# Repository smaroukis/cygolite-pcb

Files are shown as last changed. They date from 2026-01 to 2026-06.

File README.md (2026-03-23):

PCB (KiCad files + libraries) of a Cygolite bike light (white LED). Constant current driver [MIC4802YME](https://www.digikey.jp/ja/products/detail/microchip-technology/MIC4802YME/2621444) set at 750mA with Li-Ion battery connector and [MCP73831](https://www.digikey.jp/en/products/detail/microchip-technology/MCP73831T-2ACI-OT/964301) Li-Ion charger. ATTiny202 used for PWM output, status LED control and button sensing. USB-C 6P (power only) connector for charging. UART and UDPI pin headers. 

Using 0603 resistor and capacitors for best solderability + size combo.

Demonstration of circuits for multiplexing PWM<>Analog Input and Button Sense <> LED driver.

TODO add photo of the light itself

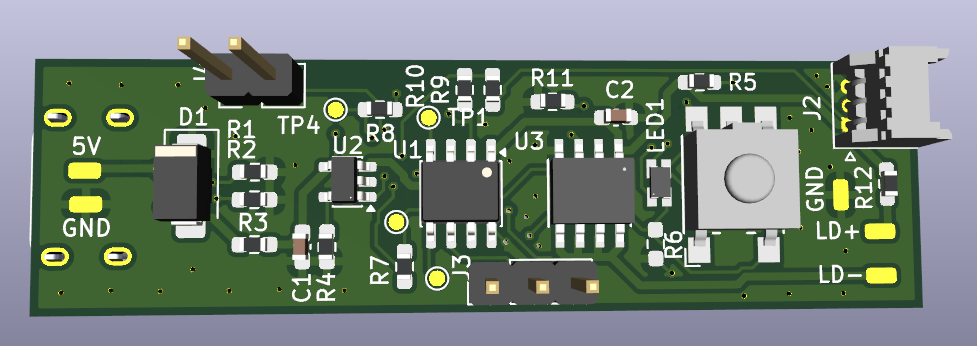
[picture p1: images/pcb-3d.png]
pcb 3d view


## Schematic and Images
See the [Schematic](Schematic.pdf) in `/Schematic.pdf`

PCB - top
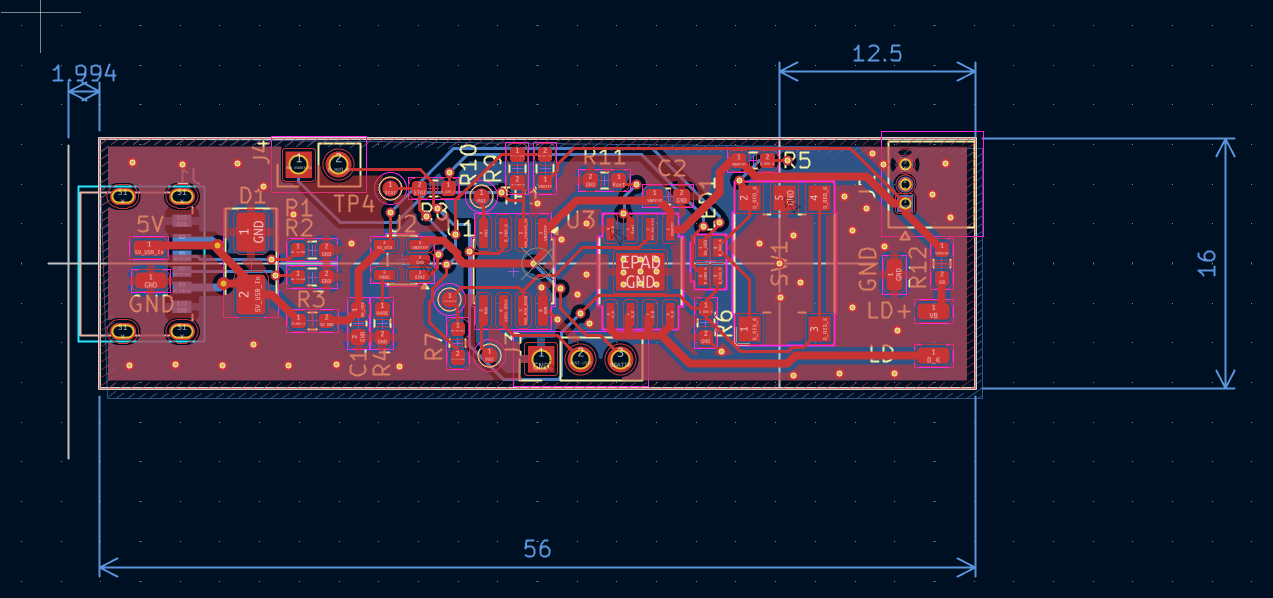
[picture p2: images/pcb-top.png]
pcb top


PCB - 3D top
pcb 3d top

PCB - 3D back (shows USB)
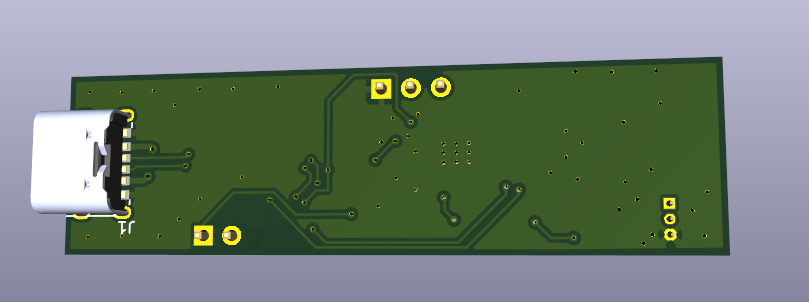
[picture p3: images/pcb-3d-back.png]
pcb 3d back


Close up of battery connector
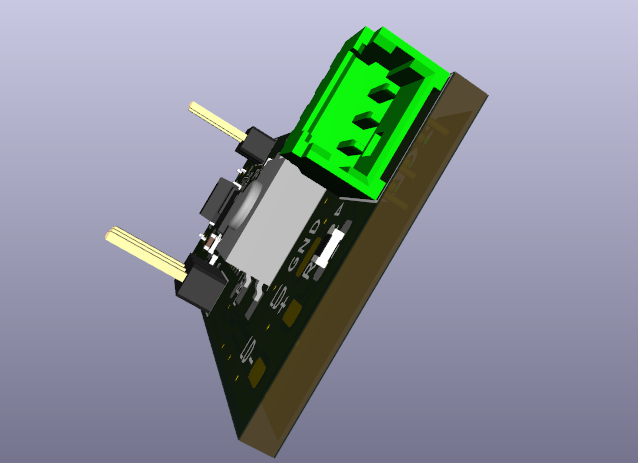
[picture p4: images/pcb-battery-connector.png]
close up battery connector


## BOM

See [BOM.csv][BOM.csv]

| Reference | Qty | Value | MPN | Manufacturer | Description |
|---|-----|---|---|---|---|
| C1,C2 | 2 | 4.7u | (Generic) | (Generic) | Unpolarized capacitor |
| D1 | 1 | SMAJ5.0CA | SMAJ5.0CA | Littelfuse | TVS DIODE 5VWM 9.2VC DO214AC |
| J1 | 1 | USB4125-GF-A-0190 | USB4125-GF-A-0190 | GCT | USB Power-Only 6P Type-C Receptacle connector |
| J2 | 1 | 530480310 | 530480310 | Molex | CONN HEADER R/A 3POS 1.25MM |
| J3 | 1 | Conn_01x03_Socket | N/A | (Generic) | Generic connector, single row, 01x03, script generated |
| J4 | 1 | Conn_01x02_Socket | N/A | (Generic) | Generic connector, single row, 01x02, script generated |
| LED1 | 1 | APHBM2012SURKCGKC | APHBM2012SURKCGKC | Kingbright | LED GREEN/RED CLEAR 2012(mm) SMD |
| R1,R2 | 2 | 5.1K | (Generic) | (Generic) | Resistor 0603 5.1K |
| R3,R12 | 2 | 0 | (Generic) | (Generic) | Resistor 0603 0Ohm |
| R4,R5,R8  | 3 | 2K | (Generic) | (Generic) | Resistor 0603 2KOhm |
| R6 | 1 | 1M | (Generic) | (Generic) | Resistor |
| R7,R9,R10 | 3 | 10K | (Generic) | (Generic) | Resistor 0603 10KOhm |
| R11 | 1 | 6.8K | (Generic) | (Generic) | Resistor 0603 6.8K 1% |
| SW1 | 1 | SW_Push | FSM1LPTR | TE Connectivity ALCOSWITCH Switches | Generic push-button switch, two contact pins and shield pin(s) |
| U1 | 1 | ATtiny202-SS | ATTINY202-SSN-ND  | Microchip Technology | 20MHz, 2kB Flash, 128B SRAM, 64B EEPROM, SOIC-8 |
| U2 | 1 | MCP73831-2-OT | MCP73831T-2ACI/OT | Microchip Technology | Single cell, Li-Ion/Li-Po charge management controller, 4.20V, Tri-State Status Output, in SOT23-5 package |
| U3 | 1 | MIC4802YME | MIC4802YME | Microchip Technology | LED Driver IC 1 Output Linear PWM Dimming 800mA 8-SOIC-EP |

## TODOs
- [ ] add schematic pdfs and board image
- [ ] add multiplexing superposition explanation

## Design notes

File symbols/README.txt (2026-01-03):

Instructions
Keep One Collocated File for all project symbols.
Append New Symbols as needed. 
Add just this .kicad_sym file to the Project's Symbol Library Path.
For auto-reuse across Projects use ${KIPRJMOD}/symbols/project_symbols.kicad_sym

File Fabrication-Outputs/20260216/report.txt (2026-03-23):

Warning: Width correction constrained.  The width correction value must be in the range of [0.000001 mm; -0.000002 mm] for the current design rules.
Plotted to '/home/spencer/Applications/KiCad/Cygolite-Clone/Fabrication-Outputs/20260216/Cygolite-Clone-F_Cu.gbr'.
Plotted to '/home/spencer/Applications/KiCad/Cygolite-Clone/Fabrication-Outputs/20260216/Cygolite-Clone-B_Cu.gbr'.
Plotted to '/home/spencer/Applications/KiCad/Cygolite-Clone/Fabrication-Outputs/20260216/Cygolite-Clone-F_Paste.gbr'.
Plotted to '/home/spencer/Applications/KiCad/Cygolite-Clone/Fabrication-Outputs/20260216/Cygolite-Clone-B_Paste.gbr'.
Plotted to '/home/spencer/Applications/KiCad/Cygolite-Clone/Fabrication-Outputs/20260216/Cygolite-Clone-F_Silkscreen.gbr'.
Plotted to '/home/spencer/Applications/KiCad/Cygolite-Clone/Fabrication-Outputs/20260216/Cygolite-Clone-B_Silkscreen.gbr'.
Plotted to '/home/spencer/Applications/KiCad/Cygolite-Clone/Fabrication-Outputs/20260216/Cygolite-Clone-F_Mask.gbr'.
Plotted to '/home/spencer/Applications/KiCad/Cygolite-Clone/Fabrication-Outputs/20260216/Cygolite-Clone-B_Mask.gbr'.
Plotted to '/home/spencer/Applications/KiCad/Cygolite-Clone/Fabrication-Outputs/20260216/Cygolite-Clone-Edge_Cuts.gbr'.
Created Gerber job file '/home/spencer/Applications/KiCad/Cygolite-Clone/Fabrication-Outputs/20260216/Cygolite-Clone-job.gbrjob'.
Info: Done.
Info: Done.

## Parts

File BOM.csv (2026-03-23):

Reference | Qty | Value | MPN | Manufacturer | Description | Footprint | Supplier 1 | Supplier 1 URL
C1,C2 | 2 | 4.7u | (Generic) | (Generic) | Unpolarized capacitor | Capacitor_SMD:C_0603_1608Metric_Pad1.08x0.95mm_HandSolder | (Generic)
D1 | 1 | SMAJ5.0CA | SMAJ5.0CA | Littelfuse | TVS DIODE 5VWM 9.2VC DO214AC | Diode_SMD:D_SMA | Digikey | https://www.digikey.jp/en/products/detail/littelfuse-inc/SMAJ5-0CA/762251
J1 | 1 | USB4125-GF-A-0190 | USB4125-GF-A-0190 | GCT | USB Power-Only 6P Type-C Receptacle connector | a_project_footprints:CONN6_125-GF-A-0190_GCT | Digikey | https://www.digikey.jp/en/products/detail/gct/USB4125-GF-A-0190/14559038
J2 | 1 | 530480310 | 530480310 | Molex | CONN HEADER R/A 3POS 1.25MM | a_project_footprints:MOLEX_530480310 | Digikey | https://www.digikey.jp/en/products/detail/molex/0530480310/242865?s=N4IgTCBcDaIKwGYAMAWAHEhBGJIC6AvkA
J3 | 1 | Conn_01x03_Socket | N/A | (Generic) | Generic connector, single row, 01x03, script generated | Connector_PinHeader_2.54mm:PinHeader_1x03_P2.54mm_Vertical | (Generic)
J4 | 1 | Conn_01x02_Socket | N/A | (Generic) | Generic connector, single row, 01x02, script generated | Connector_PinHeader_2.54mm:PinHeader_1x02_P2.54mm_Vertical | (Generic)
LED1 | 1 | APHBM2012SURKCGKC | APHBM2012SURKCGKC | Kingbright | LED GREEN/RED CLEAR 2012(mm) SMD | a_project_footprints:APHBM2012_KNB | Digikey | https://www.digikey.jp/ja/products/detail/kingbright/APHBM2012SURKCGKC/1747491
R1,R2 | 2 | 5.1K | (Generic) | (Generic) | Resistor 0603 5.1K | Resistor_SMD:R_0603_1608Metric_Pad0.98x0.95mm_HandSolder | (Generic)
R3,R12 | 2 | 0 | (Generic) | (Generic) | Resistor 0603 0Ohm | Resistor_SMD:R_0603_1608Metric_Pad0.98x0.95mm_HandSolder | (Generic)
R4,R5,R8 | 3 | 2K | (Generic) | (Generic) | Resistor 0603 2KOhm | Resistor_SMD:R_0603_1608Metric_Pad0.98x0.95mm_HandSolder | (Generic)
R6 | 1 | 1M | (Generic) | (Generic) | Resistor | Resistor_SMD:R_0603_1608Metric_Pad0.98x0.95mm_HandSolder | (Generic)
R7,R9,R10 | 3 | 10K | (Generic) | (Generic) | Resistor 0603 10KOhm | Resistor_SMD:R_0603_1608Metric_Pad0.98x0.95mm_HandSolder | (Generic)
R11 | 1 | 6.8K | (Generic) | (Generic) | Resistor 0603 6.8K 1% | Resistor_SMD:R_0603_1608Metric_Pad0.98x0.95mm_HandSolder | (Generic)
SW1 | 1 | SW_Push | FSM1LPTR | TE Connectivity ALCOSWITCH Switches | Generic push-button switch, two contact pins and shield pin(s) | a_project_footprints:SWITCH_FSM1LPA_TYC | Digikey | https://www.digikey.jp/en/products/detail/te-connectivity-alcoswitch-switches/FSM1LPTR/529676?gclsrc=aw.ds
U1 | 1 | ATtiny202-SS | ATTINY202-SSN-ND | Microchip Technology | 20MHz, 2kB Flash, 128B SRAM, 64B EEPROM, SOIC-8 | Package_SO:SOIC-8_3.9x4.9mm_P1.27mm | Digikey | https://www.digikey.jp/ja/products/detail/microchip-technology/ATTINY202-SSN/9947534
U2 | 1 | MCP73831-2-OT | MCP73831T-2ACI/OT | Microchip Technology | Single cell, Li-Ion/Li-Po charge management controller, 4.20V, Tri-State Status Output, in SOT23-5 package | Package_TO_SOT_SMD:SOT-23-5 | Digikey | https://www.digikey.jp/en/products/detail/microchip-technology/MCP73831T-2ACI-OT/964301
U3 | 1 | MIC4802YME | MIC4802YME | Microchip Technology | LED Driver IC 1 Output Linear PWM Dimming 800mA 8-SOIC-EP | a_project_footprints:SOIC-8_ME_MCL | Digikey | https://www.digikey.jp/ja/products/detail/microchip-technology/MIC4802YME/2621444

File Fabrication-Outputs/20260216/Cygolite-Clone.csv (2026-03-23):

Reference | Qty | Value | Description | Footprint | MPN | Manufacturer | Supplier 1 | Supplier 1 SKU | Supplier 1 URL
C1,C2 | 2 | 4.7u | Unpolarized capacitor | Capacitor_SMD:C_0603_1608Metric_Pad1.08x0.95mm_HandSolder | (Generic) | (Generic) | (Generic)
D1 | 1 | SMAJ5.0CA | TVS DIODE 5VWM 9.2VC DO214AC | Diode_SMD:D_SMA | SMAJ5.0CA | Littelfuse | Digikey |  | https://www.digikey.jp/en/products/detail/littelfuse-inc/SMAJ5-0CA/762251
J1 | 1 | USB4125-GF-A-0190 | USB Power-Only 6P Type-C Receptacle connector | a_project_footprints:CONN6_125-GF-A-0190_GCT | USB4125-GF-A-0190 | GCT | Digikey |  | https://www.digikey.jp/en/products/detail/gct/USB4125-GF-A-0190/14559038
J2 | 1 | 530480310 | CONN HEADER R/A 3POS 1.25MM | a_project_footprints:MOLEX_530480310 | 530480310 | Molex | Digikey |  | https://www.digikey.jp/en/products/detail/molex/0530480310/242865?s=N4IgTCBcDaIKwGYAMAWAHEhBGJIC6AvkA
J3 | 1 | Conn_01x03_Socket | Generic connector, single row, 01x03, script generated | Connector_PinHeader_2.54mm:PinHeader_1x03_P2.54mm_Vertical | N/A
J4 | 1 | Conn_01x02_Socket | Generic connector, single row, 01x02, script generated | Connector_PinHeader_2.54mm:PinHeader_1x02_P2.54mm_Vertical | N/A
LED1 | 1 | APHBM2012SURKCGKC | LED GREEN/RED CLEAR 2012(mm) SMD | a_project_footprints:APHBM2012_KNB | APHBM2012SURKCGKC | Kingbright | Digikey |  | https://www.digikey.jp/ja/products/detail/kingbright/APHBM2012SURKCGKC/1747491
R1,R2 | 2 | 5.1K | Resistor 0603 5.1K | Resistor_SMD:R_0603_1608Metric_Pad0.98x0.95mm_HandSolder | (Generic)
R3,R12 | 2 | 0 | Resistor 0603 0Ohm | Resistor_SMD:R_0603_1608Metric_Pad0.98x0.95mm_HandSolder | (Generic)
R4,R5,R8 | 3 | 2K | Resistor 0603 2KOhm | Resistor_SMD:R_0603_1608Metric_Pad0.98x0.95mm_HandSolder | (Generic) | (Generic) | (Generic)
R6 | 1 | 1M | Resistor | Resistor_SMD:R_0603_1608Metric_Pad0.98x0.95mm_HandSolder | (Generic) | (Generic) | (Generic)
R7,R9,R10 | 3 | 10K | Resistor 0603 10KOhm | Resistor_SMD:R_0603_1608Metric_Pad0.98x0.95mm_HandSolder | (Generic) | (Generic) | (Generic)
R11 | 1 | 6.8K | Resistor 0603 6.8K 1% | Resistor_SMD:R_0603_1608Metric_Pad0.98x0.95mm_HandSolder | (Generic) | (Generic) | (Generic)
SP1 | 1 | P+ | test point | Connector_Wire:SolderWirePad_1x01_SMD_1x2mm | N/A
SP2 | 1 | P- | test point | Connector_Wire:SolderWirePad_1x01_SMD_1x2mm | N/A
SP3 | 1 | GND | test point | Connector_Wire:SolderWirePad_1x01_SMD_1x2mm | N/A
SP4 | 1 | 5V | test point | Connector_Wire:SolderWirePad_1x01_SMD_1x2mm | N/A
SP6 | 1 | LED_K | test point | Connector_Wire:SolderWirePad_1x01_SMD_1x2mm | N/A
SW1 | 1 | SW_Push | Generic push-button switch, two contact pins and shield pin(s) | a_project_footprints:SWITCH_FSM1LPA_TYC | FSM1LPTR | TE Connectivity ALCOSWITCH Switches | Digikey |  | https://www.digikey.jp/en/products/detail/te-connectivity-alcoswitch-switches/FSM1LPTR/529676?gclsrc=aw.ds
TP1,TP2,TP3 | 3 | U2_VDD | test point | TestPoint:TestPoint_Pad_D1.0mm | N/A
TP4 | 1 | STAT | test point | TestPoint:TestPoint_Pad_D1.0mm | N/A
U1 | 1 | ATtiny202-SS | 20MHz, 2kB Flash, 128B SRAM, 64B EEPROM, SOIC-8 | Package_SO:SOIC-8_3.9x4.9mm_P1.27mm | ATTINY202-SSN-ND | Microchip Technology | Digikey |  | https://www.digikey.jp/ja/products/detail/microchip-technology/ATTINY202-SSN/9947534
U2 | 1 | MCP73831-2-OT | Single cell, Li-Ion/Li-Po charge management controller, 4.20V, Tri-State Status Output, in SOT23-5 package | Package_TO_SOT_SMD:SOT-23-5 | MCP73831T-2ACI/OT | Microchip Technology | Digikey |  | https://www.digikey.jp/en/products/detail/microchip-technology/MCP73831T-2ACI-OT/964301
U3 | 1 | MIC4802YME | LED Driver IC 1 Output Linear PWM Dimming 800mA 8-SOIC-EP | a_project_footprints:SOIC-8_ME_MCL | MIC4802YME | Microchip Technology | Digikey |  | https://www.digikey.jp/ja/products/detail/microchip-technology/MIC4802YME/2621444

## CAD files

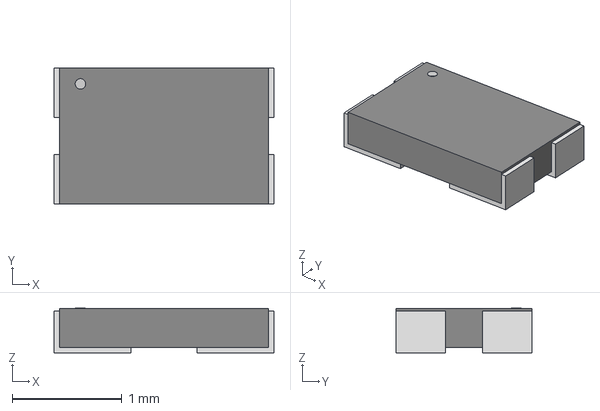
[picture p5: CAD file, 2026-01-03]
3dmodels/APHBM2012_KNB.step
2.01 x 1.24 x 0.409 mm

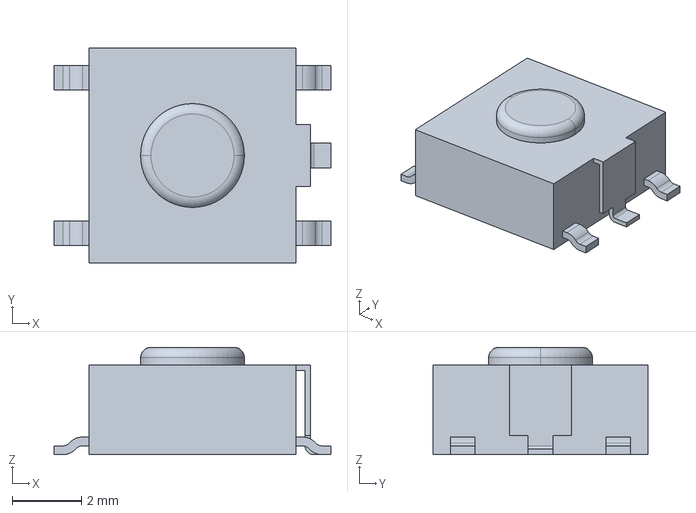
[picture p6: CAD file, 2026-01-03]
imports_source/FSM1LPTR/FSM1LPTR_PB_c-1-1437565-9-d1-3d.stp
8.00 x 6.20 x 3.10 mm

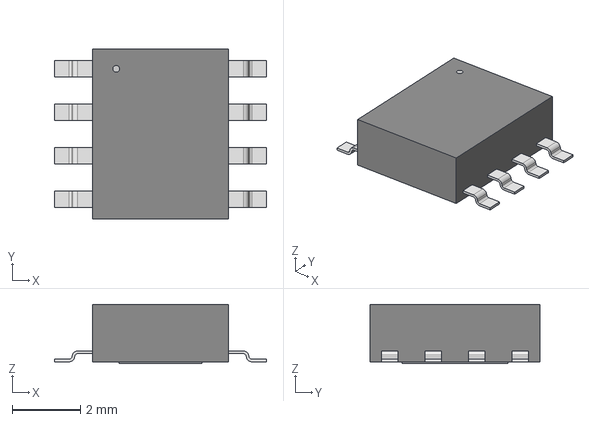
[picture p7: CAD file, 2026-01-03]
imports_source/MIC4802YME/SOIC-8_ME_MCL.step
6.20 x 4.98 x 1.73 mm

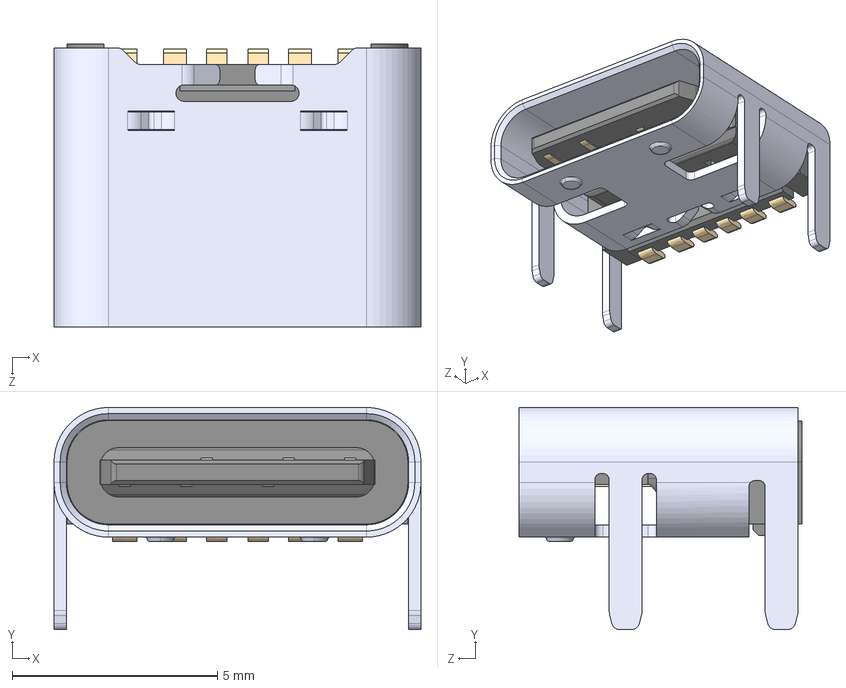
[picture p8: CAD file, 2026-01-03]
imports_source/USB4125_GF_A_0190/USB4125-GF-A-0190_REVA2.step
8.94 x 5.41 x 6.90 mm

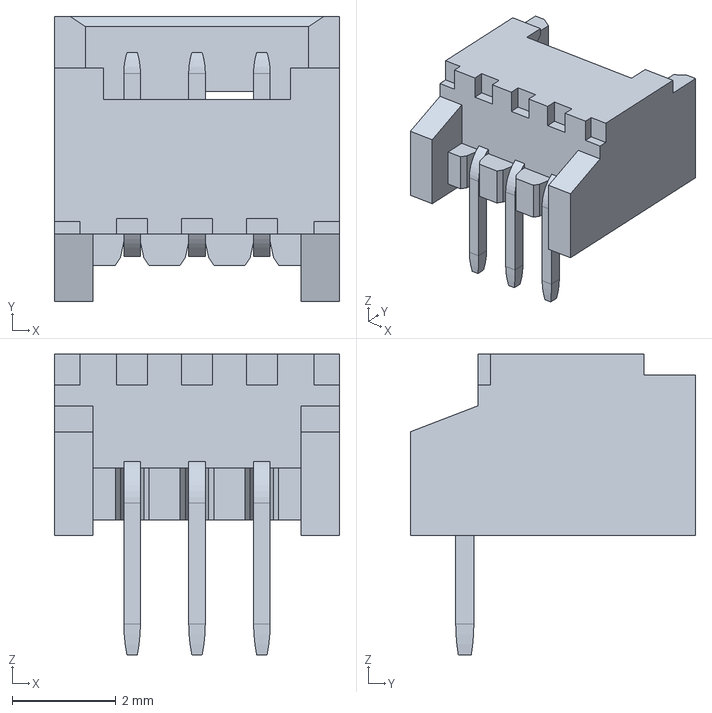
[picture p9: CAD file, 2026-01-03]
imports_source/Molex_530480310/530480310.step
5.50 x 5.50 x 5.80 mm

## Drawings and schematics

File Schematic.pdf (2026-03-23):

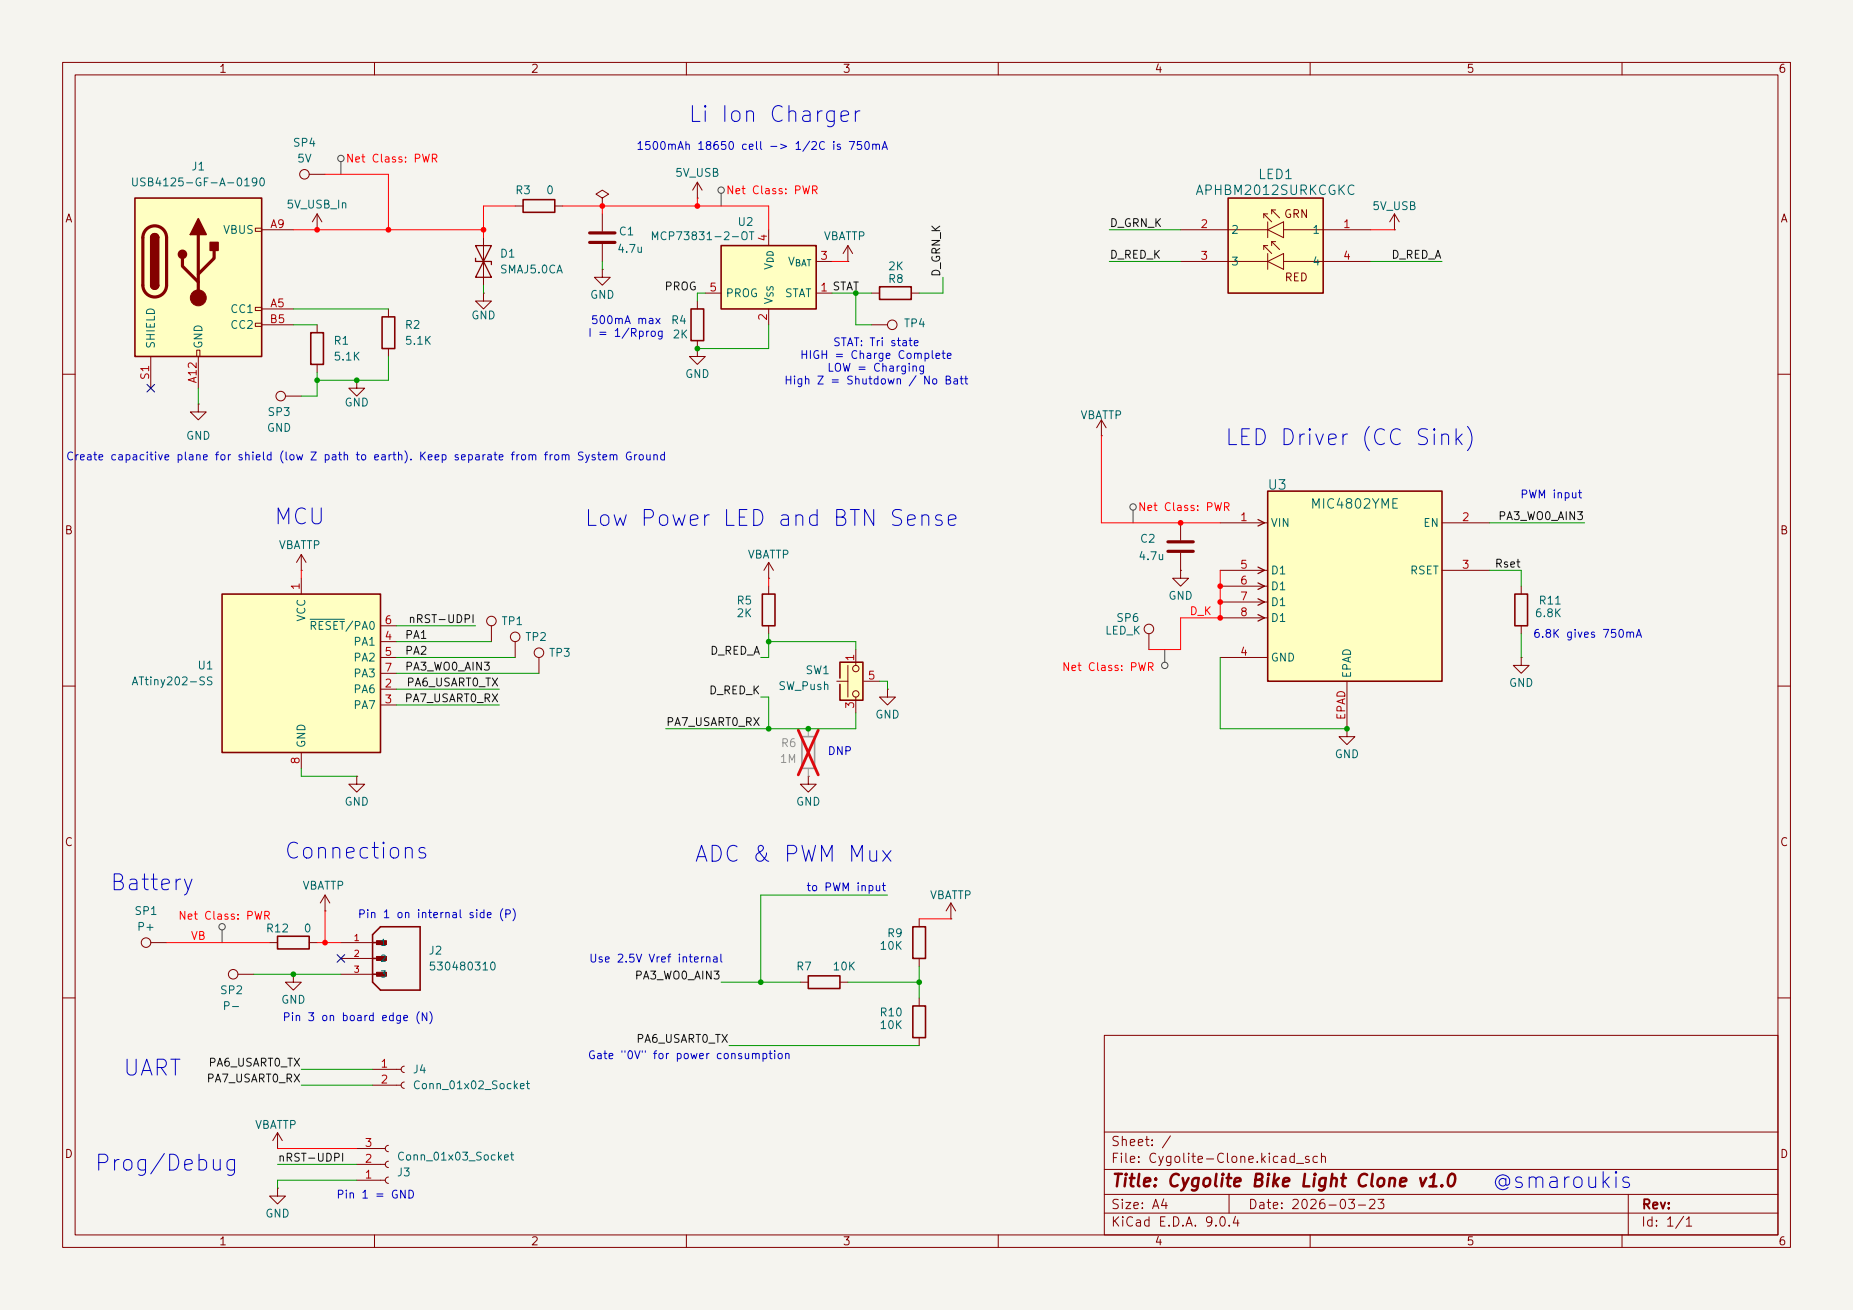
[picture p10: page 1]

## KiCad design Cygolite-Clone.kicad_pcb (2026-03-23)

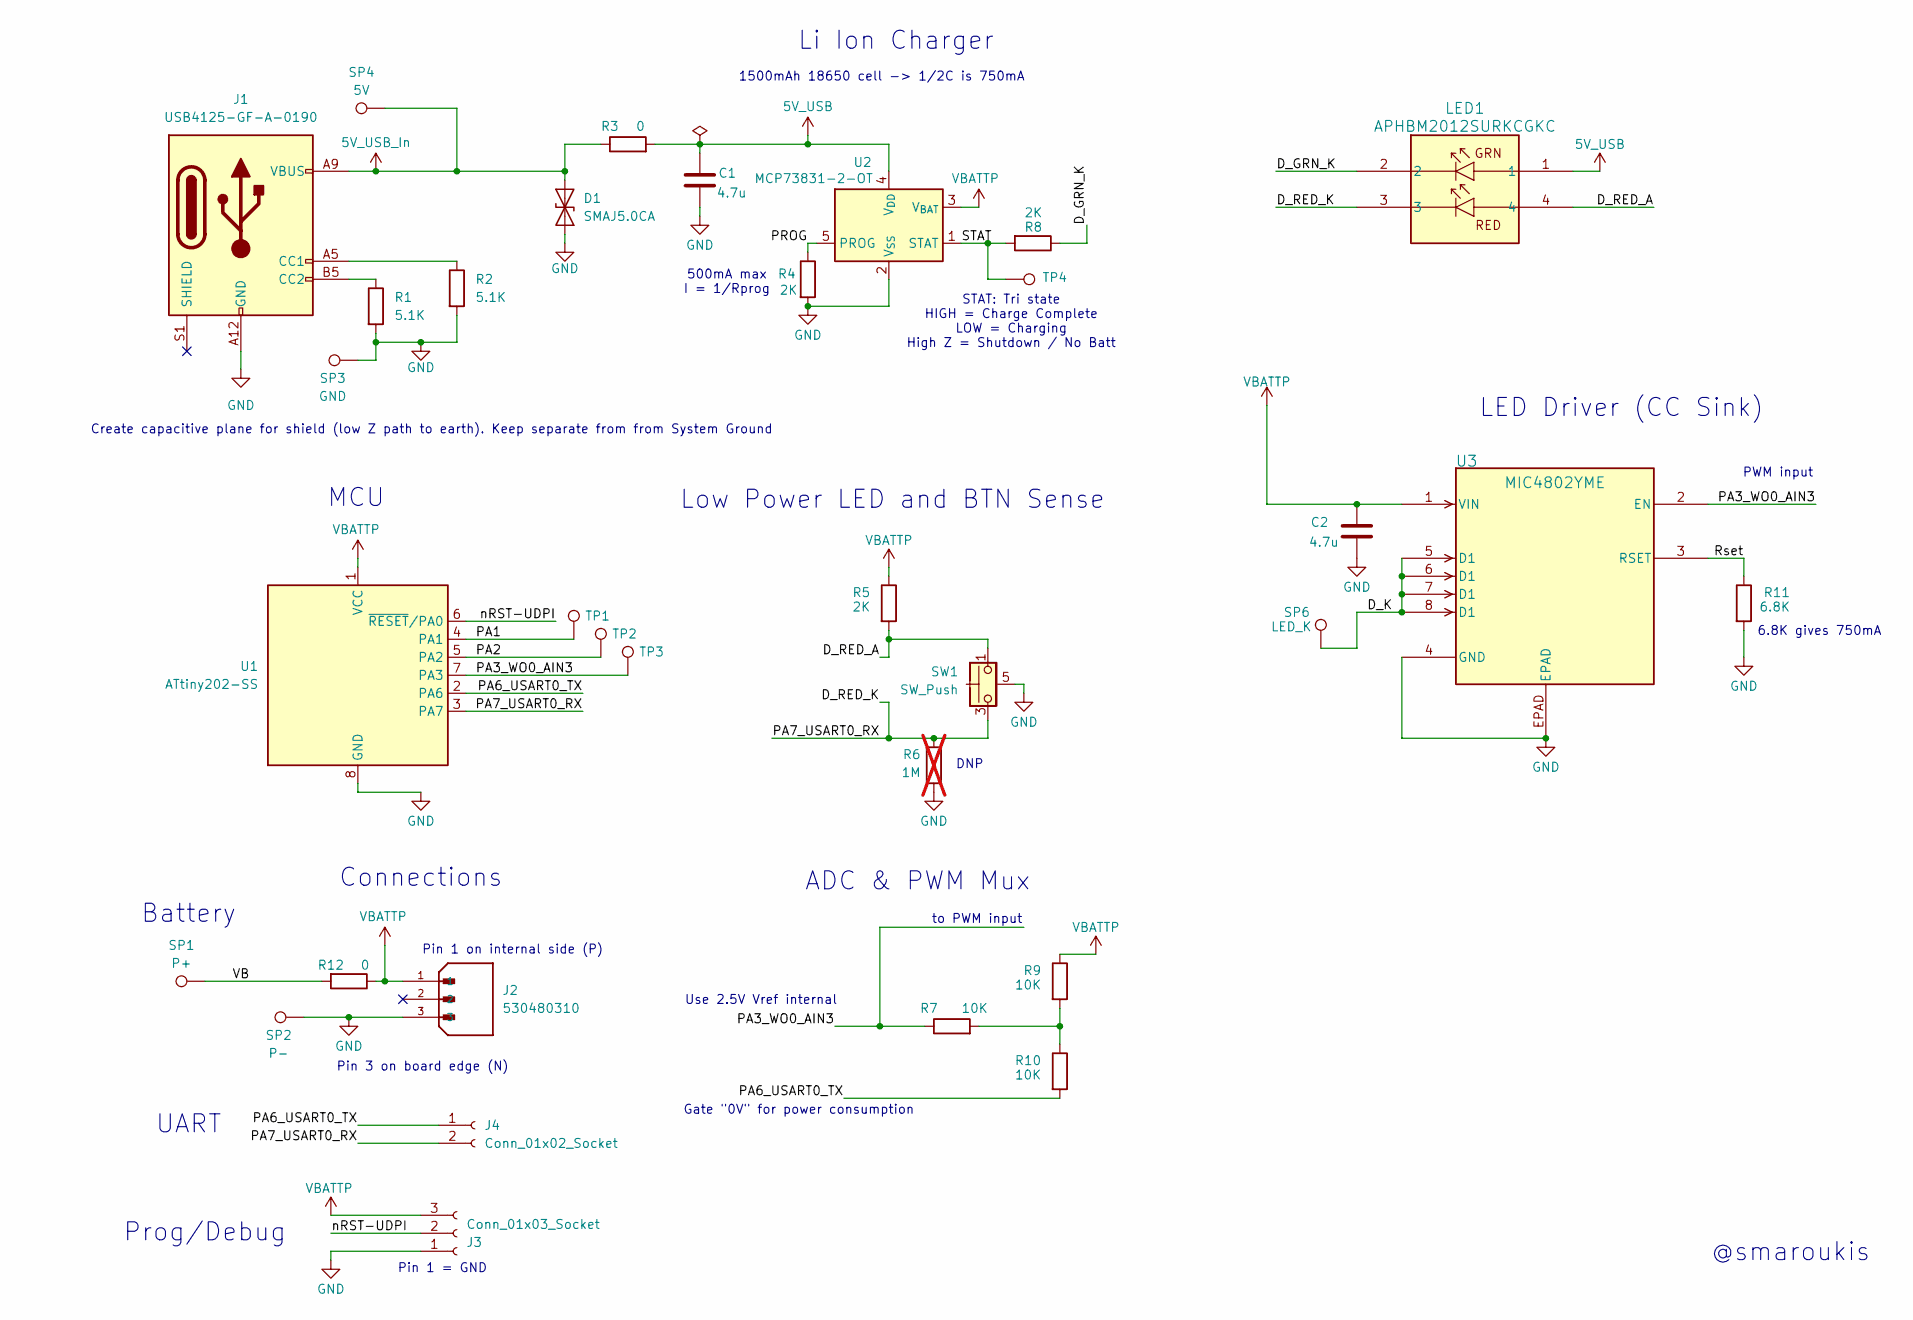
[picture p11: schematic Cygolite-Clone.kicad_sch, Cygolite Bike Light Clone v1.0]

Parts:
C1, C2: 4.7u; C_0603_1608Metric_Pad1.08x0.95mm_HandSolder; MPN (Generic)
D1: SMAJ5.0CA; D_SMA; MPN SMAJ5.0CA
J1: USB4125-GF-A-0190; CONN6_125-GF-A-0190_GCT; MPN USB4125-GF-A-0190
J2: 530480310; MOLEX_530480310; PARTREV A
J3: Conn_01x03_Socket; PinHeader_1x03_P2.54mm_Vertical; MPN N/A
J4: Conn_01x02_Socket; PinHeader_1x02_P2.54mm_Vertical; MPN N/A
LED1: APHBM2012SURKCGKC; APHBM2012_KNB; MPN APHBM2012SURKCGKC
R1, R2: 5.1K; R_0603_1608Metric_Pad0.98x0.95mm_HandSolder; MPN (Generic)
R3, R12: 0; R_0603_1608Metric_Pad0.98x0.95mm_HandSolder; MPN (Generic)
R4, R5, R8: 2K; R_0603_1608Metric_Pad0.98x0.95mm_HandSolder; MPN (Generic)
R6: 1M; R_0603_1608Metric_Pad0.98x0.95mm_HandSolder; MPN (Generic); not fitted
R7, R9, R10: 10K; R_0603_1608Metric_Pad0.98x0.95mm_HandSolder; MPN (Generic)
R11: 6.8K; R_0603_1608Metric_Pad0.98x0.95mm_HandSolder; MPN (Generic)
SP1: P+; SolderWirePad_1x01_SMD_1x2mm; MPN N/A
SP2: P-; SolderWirePad_1x01_SMD_1x2mm; MPN N/A
SP3: GND; SolderWirePad_1x01_SMD_1x2mm; MPN N/A
SP4: 5V; SolderWirePad_1x01_SMD_1x2mm; MPN N/A
SP6: LED_K; SolderWirePad_1x01_SMD_1x2mm; MPN N/A
SW1: SW_Push; SWITCH_FSM1LPA_TYC; MPN FSM1LPTR
TP1, TP2, TP3: U2_VDD; TestPoint_Pad_D1.0mm; MPN N/A
TP4: STAT; TestPoint_Pad_D1.0mm; MPN N/A
U1: ATtiny202-SS; SOIC-8_3.9x4.9mm_P1.27mm; MPN ATTINY202-SSN-ND
U2: MCP73831-2-OT; SOT-23-5; MPN MCP73831T-2ACI/OT
U3: MIC4802YME; SOIC-8_ME_MCL; MPN MIC4802YME

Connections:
5V_USB: C1.1, LED1.1, R3.2, U2.4 (V_{DD})
5V_USB_In: D1.2 (A2), J1.A9 (VBUS), J1.B9 (VBUS), R3.1, SP4.1
/D_GRN_K: LED1.2, R8.1
/D_K: SP6.1, U3.5 (D1), U3.6 (D1), U3.7 (D1), U3.8 (D1)
/D_RED_A: LED1.4, R5.2, SW1.1, SW1.2
/D_RED_K: J4.2, LED1.3, R6.1, SW1.3, SW1.4, U1.3 (PA7)
/PA1: TP1.1, U1.4 (PA1)
/PA2: TP2.1, U1.5 (PA2)
/PA3_WO0_AIN3: R7.1, TP3.1, U1.7 (PA3), U3.2 (EN)
/PA6_USART0_TX: J4.1, R10.2, U1.2 (PA6)
/PROG: R4.1, U2.5 (PROG)
/Rset: R11.1, U3.3 (RSET)
/STAT: R8.2, TP4.1, U2.1 (STAT)
/VB: R12.2, SP1.1
/nRST-UDPI: J3.2, U1.6 (~RESET/PA0)
GND: C1.2, C2.2, D1.1 (A1), J1.A12 (GND), J1.B12 (GND), J2.3, J3.1, R1.2, R2.2, R4.2, R6.2, R11.2, SP2.1, SP3.1, SW1.5 (SHD), U1.8 (GND), U2.2 (V_{SS}), U3.4 (GND), U3.EPAD
unnamed: J1.A5 (CC1), R2.1
unnamed: J1.B5 (CC2), R1.1
unnamed: R7.2, R9.2, R10.1
VBATTP: C2.1, J2.1, J3.3, R5.1, R9.1, R12.1, U1.1 (VCC), U2.3 (V_{BAT}), U3.1 (VIN)

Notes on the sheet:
500mA max I = 1/Rprog
STAT: Tri state HIGH = Charge Complete LOW = Charging High Z = Shutdown / No Batt
Use 2.5V Vref internal
Li Ion Charger
6.8K gives 750mA
Pin 1 on internal side (P)
Low Power LED and BTN Sense
Prog/Debug
MCU
LED Driver (CC Sink)
ADC & PWM Mux
Pin 3 on board edge (N)
Gate "0V" for power consumption
Connections
Create capacitive plane for shield (low Z path to earth). Keep separate from from System Ground
to PWM input
DNP
Pin 1 = GND
Battery
1500mAh 18650 cell -> 1/2C is 750mA
PWM input
@smaroukis
UART

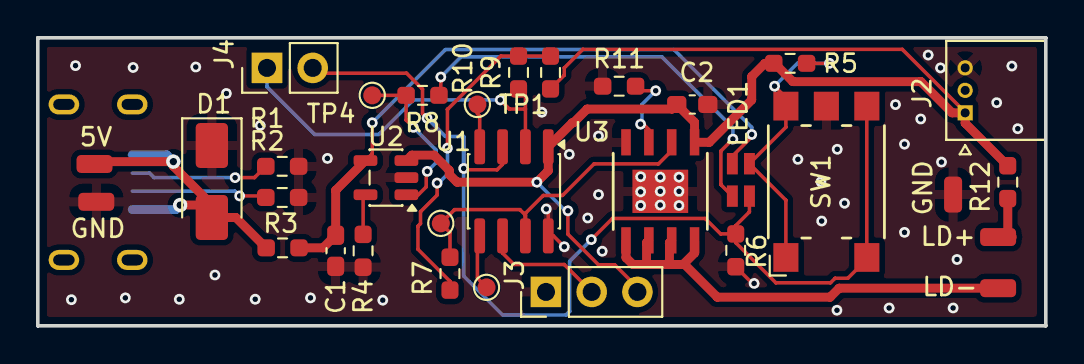
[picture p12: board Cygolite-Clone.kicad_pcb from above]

Board: 2 copper layers, 56.0 x 16.0 mm, 33 parts (1 on the bottom side), 20 nets.

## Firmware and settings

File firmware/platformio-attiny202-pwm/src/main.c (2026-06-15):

// Integrated read battery voltage as self contained function, requires battery.c
#define F_CPU 3333333UL

#include <avr/io.h>
#include <stdint.h>
#include <stdbool.h>

#include "uart0.h"
#include "pwm0.h"
#include "battery.h"

static const uint8_t duty_steps[] = {
    0,
    64,
    128,
    192,
    255
};

#define DUTY_STEP_COUNT (sizeof(duty_steps) / sizeof(duty_steps[0]))

static uint8_t duty_index = 0;

static void print_help(void) {
    uart0_print("\r\n");
    uart0_print("battery mux test\r\n");
    uart0_print("commands:\r\n");
    uart0_print("  0 = 0% duty\r\n");
    uart0_print("  1 = 25% duty\r\n");
    uart0_print("  2 = 50% duty\r\n");
    uart0_print("  3 = 75% duty\r\n");
    uart0_print("  4 = 100% duty\r\n");
    uart0_print("  b = muxed battery/ADC read\r\n");
    uart0_print("  s = status\r\n");
    uart0_print("  ? = help\r\n");
    uart0_print("\r\n");
}

static void apply_duty(void) {
    pwm0_set_duty_8bit(duty_steps[duty_index]);
}

static void print_status(void) {
    uart0_print("duty_index=");
    uart0_print_u16(duty_index);

    uart0_print(" duty=");
    uart0_print_u16(duty_steps[duty_index]);

    uart0_print("\r\n");
}

// TODO - this actualy performs two ADC reads (read_muxed_raw and read_muxed_battery) - add a pub fn to convert raw without another read
static void read_battery(void) {
    uint16_t raw = battery_read_muxed_pa3_raw();
    uint16_t pin_mv = adc0_raw_to_mv(raw);
    uint16_t battery_mv = battery_read_muxed_pa3_battery_mv();

    uart0_print("battery mux read: raw=");
    uart0_print_u16(raw);

    uart0_print(" pin_mv=");
    uart0_print_u16(pin_mv);

    uart0_print(" battery_mv=");
    uart0_print_u16(battery_mv);

    uart0_print(" restored_duty=");
    uart0_print_u16(pwm0_get_duty_8bit());

    uart0_print("\r\n");
}

static void handle_command(char c) {
    if (c == '\r' || c == '\n') {
        return;
    }

    if (c >= '0' && c <= '4') {
        duty_index = c - '0';
        apply_duty();
        print_status();
        return;
    }

    switch (c) {
        case 'b':
            read_battery();
            break;

        case 's':
            print_status();
            break;

        case '?':
            print_help();
            print_status();
            break;

        default:
            uart0_print("unknown command\r\n");
            break;
    }
}

int main(void) {
    uart0_init();
    pwm0_init_pa3();
    battery_init();

    duty_index = 0;
    apply_duty();

    uart0_print("\r\nboot: battery mux test\r\n");
    print_help();
    print_status();

    while (1) {
        char c;

        if (uart0_try_getc(&c)) {
            handle_command(c);
        }
    }
}

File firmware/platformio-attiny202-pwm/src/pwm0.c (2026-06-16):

#include "pwm0.h"

#include <avr/io.h>
#include <stdint.h>

#define PWM0_PIN_bm PIN3_bm   // PA3 / TCA0 WO0
static uint8_t pwm0_current_duty = 0;

void pwm0_init_pa3(void) {
    // PA3 output
    PORTA.DIRSET = PWM0_PIN_bm;

    // Stop TCA0 while configuring.
    TCA0.SINGLE.CTRLA = 0;

    /*
     * Single-slope PWM.
     * Enable compare channel 0 output = WO0 on PA3.
     */
    TCA0.SINGLE.CTRLB =
        TCA_SINGLE_WGMODE_SINGLESLOPE_gc |
        TCA_SINGLE_CMP0EN_bm;

    /*
     * 8-bit-style PWM period.
     *
     * With F_CPU ≈ 3.333 MHz:
     *   PWM frequency ≈ 3,333,333 / 256
     *   PWM frequency ≈ 13 kHz
     */
    TCA0.SINGLE.PER = 255;

    // Start at 0% duty.
    TCA0.SINGLE.CMP0 = 0;

    // Start timer, no prescaler.
    TCA0.SINGLE.CTRLA =
        TCA_SINGLE_CLKSEL_DIV1_gc |
        TCA_SINGLE_ENABLE_bm;


    pwm0_set_duty_8bit(0);
}

void pwm0_set_duty_8bit(uint8_t duty) {
    pwm0_current_duty = duty;

    // Make sure PA3 is an output.
    PORTA.DIRSET = PWM0_PIN_bm;

    if (duty == 0) {
        /*
         * True OFF:
         * disconnect TCA0 from PA3 and force PA3 LOW.
         */
        TCA0.SINGLE.CTRLB &= ~TCA_SINGLE_CMP0EN_bm;
        PORTA.OUTCLR = PWM0_PIN_bm;
        return;
    }

    if (duty >= 255) {
        /*
         * True FULL ON:
         * disconnect TCA0 from PA3 and force PA3 HIGH.
         */
        TCA0.SINGLE.CTRLB &= ~TCA_SINGLE_CMP0EN_bm;
        PORTA.OUTSET = PWM0_PIN_bm;
        return;
    }

    /*
     * Normal PWM range.
     */
    TCA0.SINGLE.CMP0 = duty;
    TCA0.SINGLE.CTRLB |= TCA_SINGLE_CMP0EN_bm;
}

uint8_t pwm0_get_duty_8bit(void) {
    return pwm0_current_duty;
}

void pwm0_disable_pa3_output(void) {
    /*
     * Disconnect TCA0 compare channel 0 from PA3.
     * Do not change pwm0_current_duty, because this may be temporary.
     */
    TCA0.SINGLE.CTRLB &= ~TCA_SINGLE_CMP0EN_bm;

    // Force PA3 low while disabled.
    PORTA.DIRSET = PWM0_PIN_bm;
    PORTA.OUTCLR = PWM0_PIN_bm;
}

void pwm0_enable_pa3_output(void) {
    /*
     * Restore PA3 output according to the remembered duty.
     * This correctly handles 0%, 100%, and middle PWM values.
     */
    PORTA.DIRSET = PWM0_PIN_bm;
    pwm0_set_duty_8bit(pwm0_current_duty);
}

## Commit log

2026-01-12 added images, schematic, updated readme
2026-03-23 added v1.0 as built files
    [BOM.csv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]
2026-06-15 fab outputs and pedagogical baremetal drivers
    [Cygolite-Clone.csv]
2026-06-15 example app 8 - debounce button press (active high)
2026-06-15 app 9 button input with pressed timer
2026-06-15 light controller uart print
